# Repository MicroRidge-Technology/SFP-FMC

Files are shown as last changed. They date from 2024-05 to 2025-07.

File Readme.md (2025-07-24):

# FMC SFP Card

This project is designed to allow using sfp cables with the LVDS pins of an FPGA as opposed to the GTX pins. It provides testpoints to monitor the lvds signals with an oscilliscope.

# Pins Used

| FMC Pin | Logical Name | SFP Channel |
| --- | --- | --- |
| D14 | FMC\_LA09\_P | SFP0 rx+ |
| D15 | FMC\_LA09\_N | SFP0 rx- |
| H7 | FMC\_LA02\_P | SFP0 tx+ |
| H8 | FMC\_LA02\_N | SFP0 tx- |
| H22 | FMC\_LA19\_P | SFP1 rx+ |
| H23 | FMC\_LA19\_N | SFP1 rx- |
| H37 | FMC\_LA32\_P | SFP1 tx+ |
| H38 | FMC\_LA32\_N | SFP1 tx- |

# Schematics
Schmatics are available [here](doc/fmc-sfp.pdf)

# Images

Top
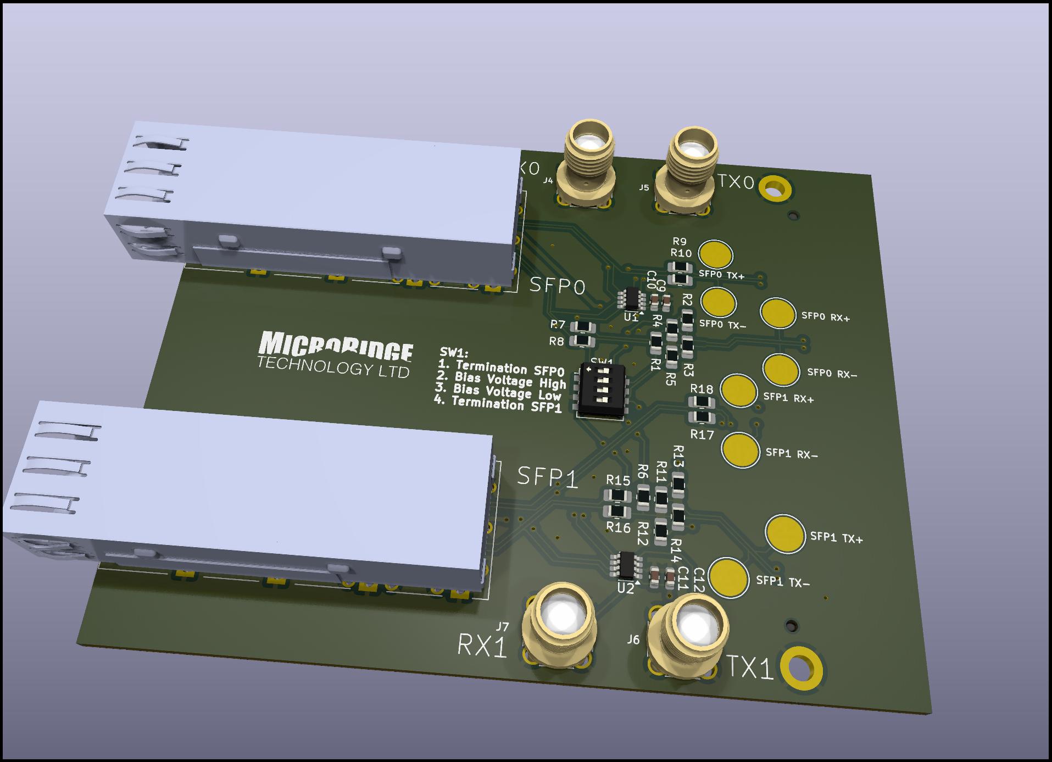
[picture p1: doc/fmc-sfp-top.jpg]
top


Bottom
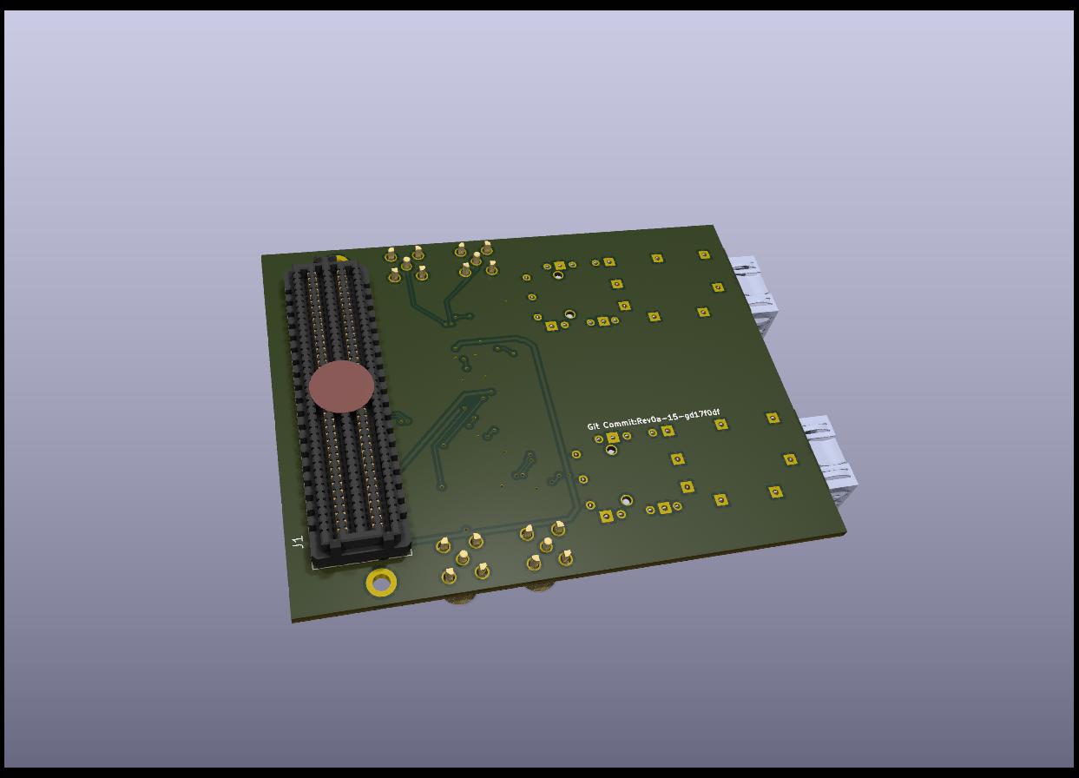
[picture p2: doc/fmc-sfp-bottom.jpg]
bottom


# Limitations 

This board is designed to work with low frequency signals (<200MHz)  GHz+ signals will certainly fail.

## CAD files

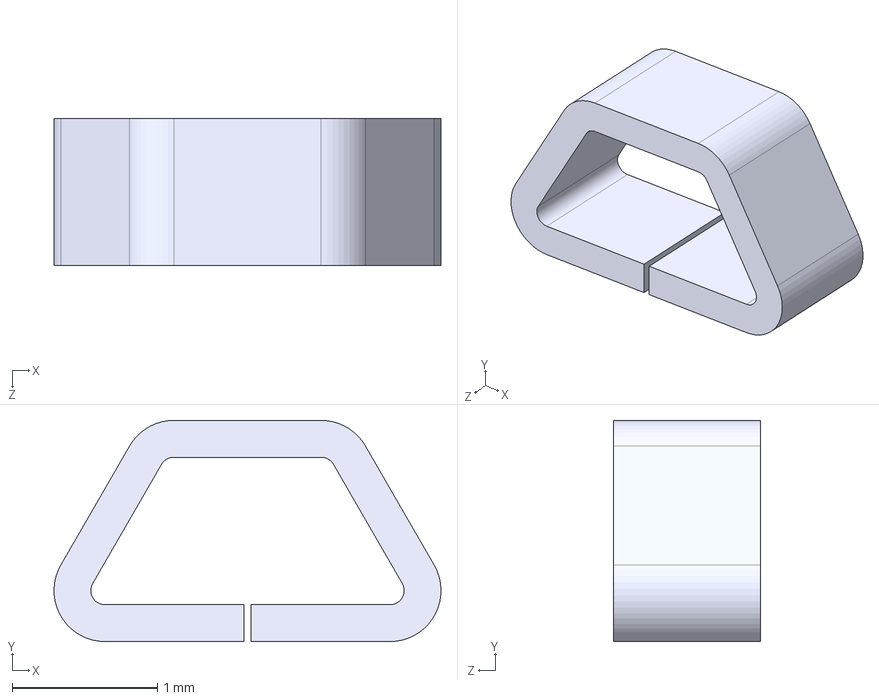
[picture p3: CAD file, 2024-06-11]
3d-models/5015.step
2.67 x 1.52 x 1.02 mm

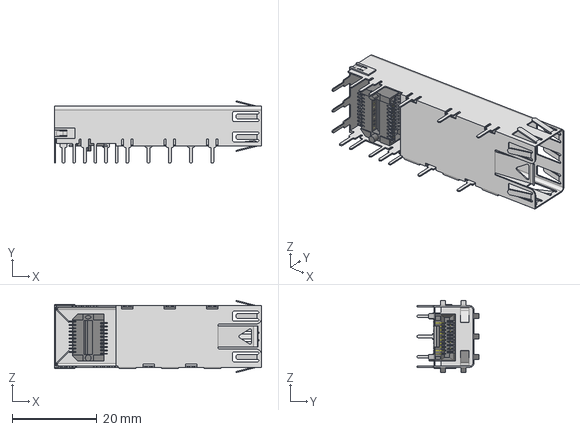
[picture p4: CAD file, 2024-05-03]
3d-models/sfpk-sl.step
48.7 x 14.7 x 17.0 mm

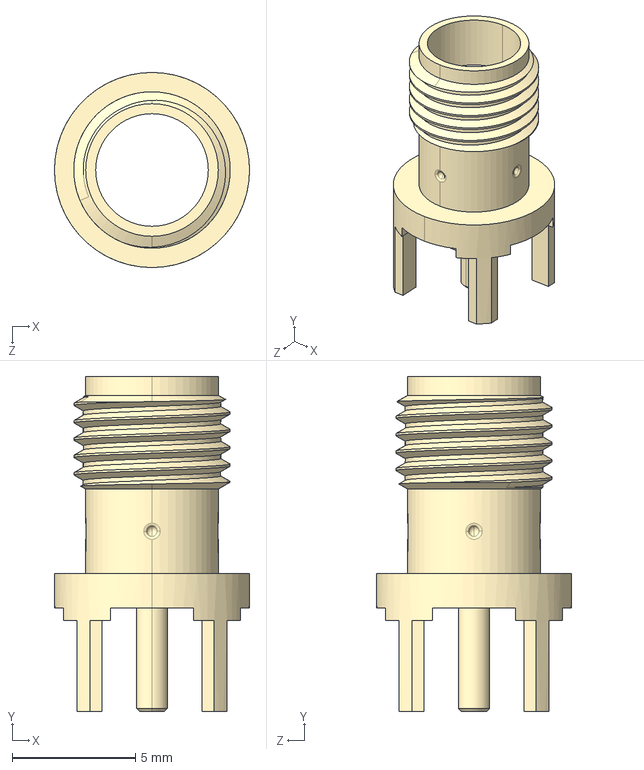
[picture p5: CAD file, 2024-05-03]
3d-models/SMA.step
7.92 x 13.6 x 7.92 mm

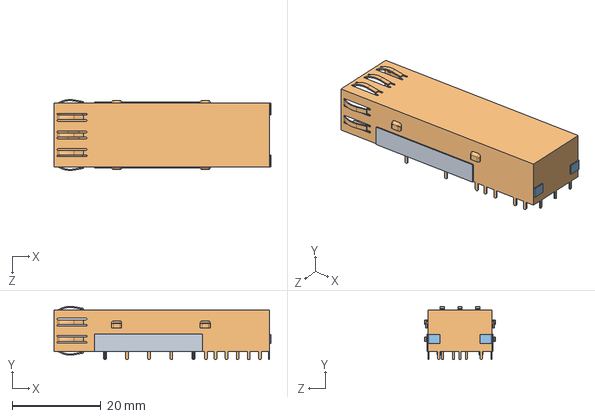
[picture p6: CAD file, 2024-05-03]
3d-models/SFP_cage.step
49.0 x 12.0 x 16.0 mm

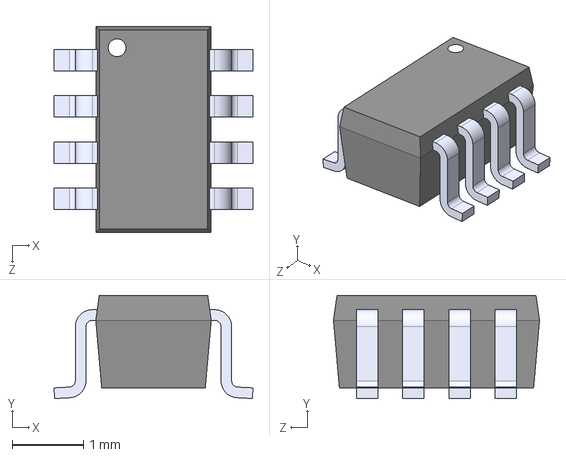
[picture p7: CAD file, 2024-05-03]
3d-models/MAX9113EKA_TT.step
2.80 x 1.45 x 2.90 mm

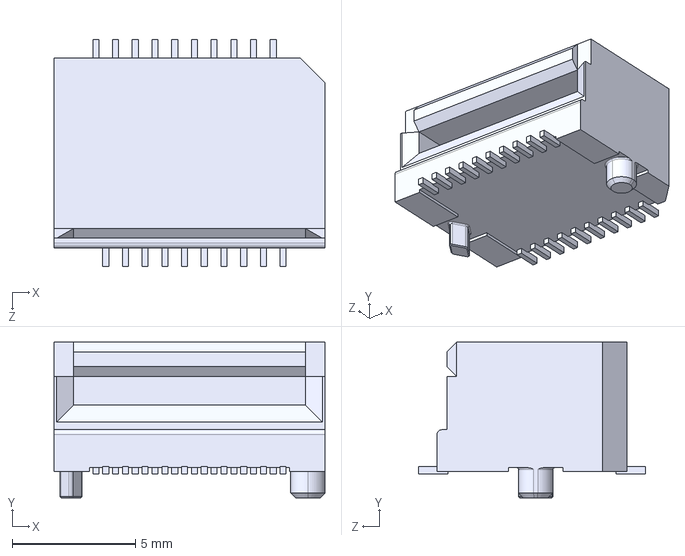
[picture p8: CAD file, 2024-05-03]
3d-models/SFP_connector.step
11.0 x 6.33 x 9.20 mm
UE75A20xxxxx
PinsT_def

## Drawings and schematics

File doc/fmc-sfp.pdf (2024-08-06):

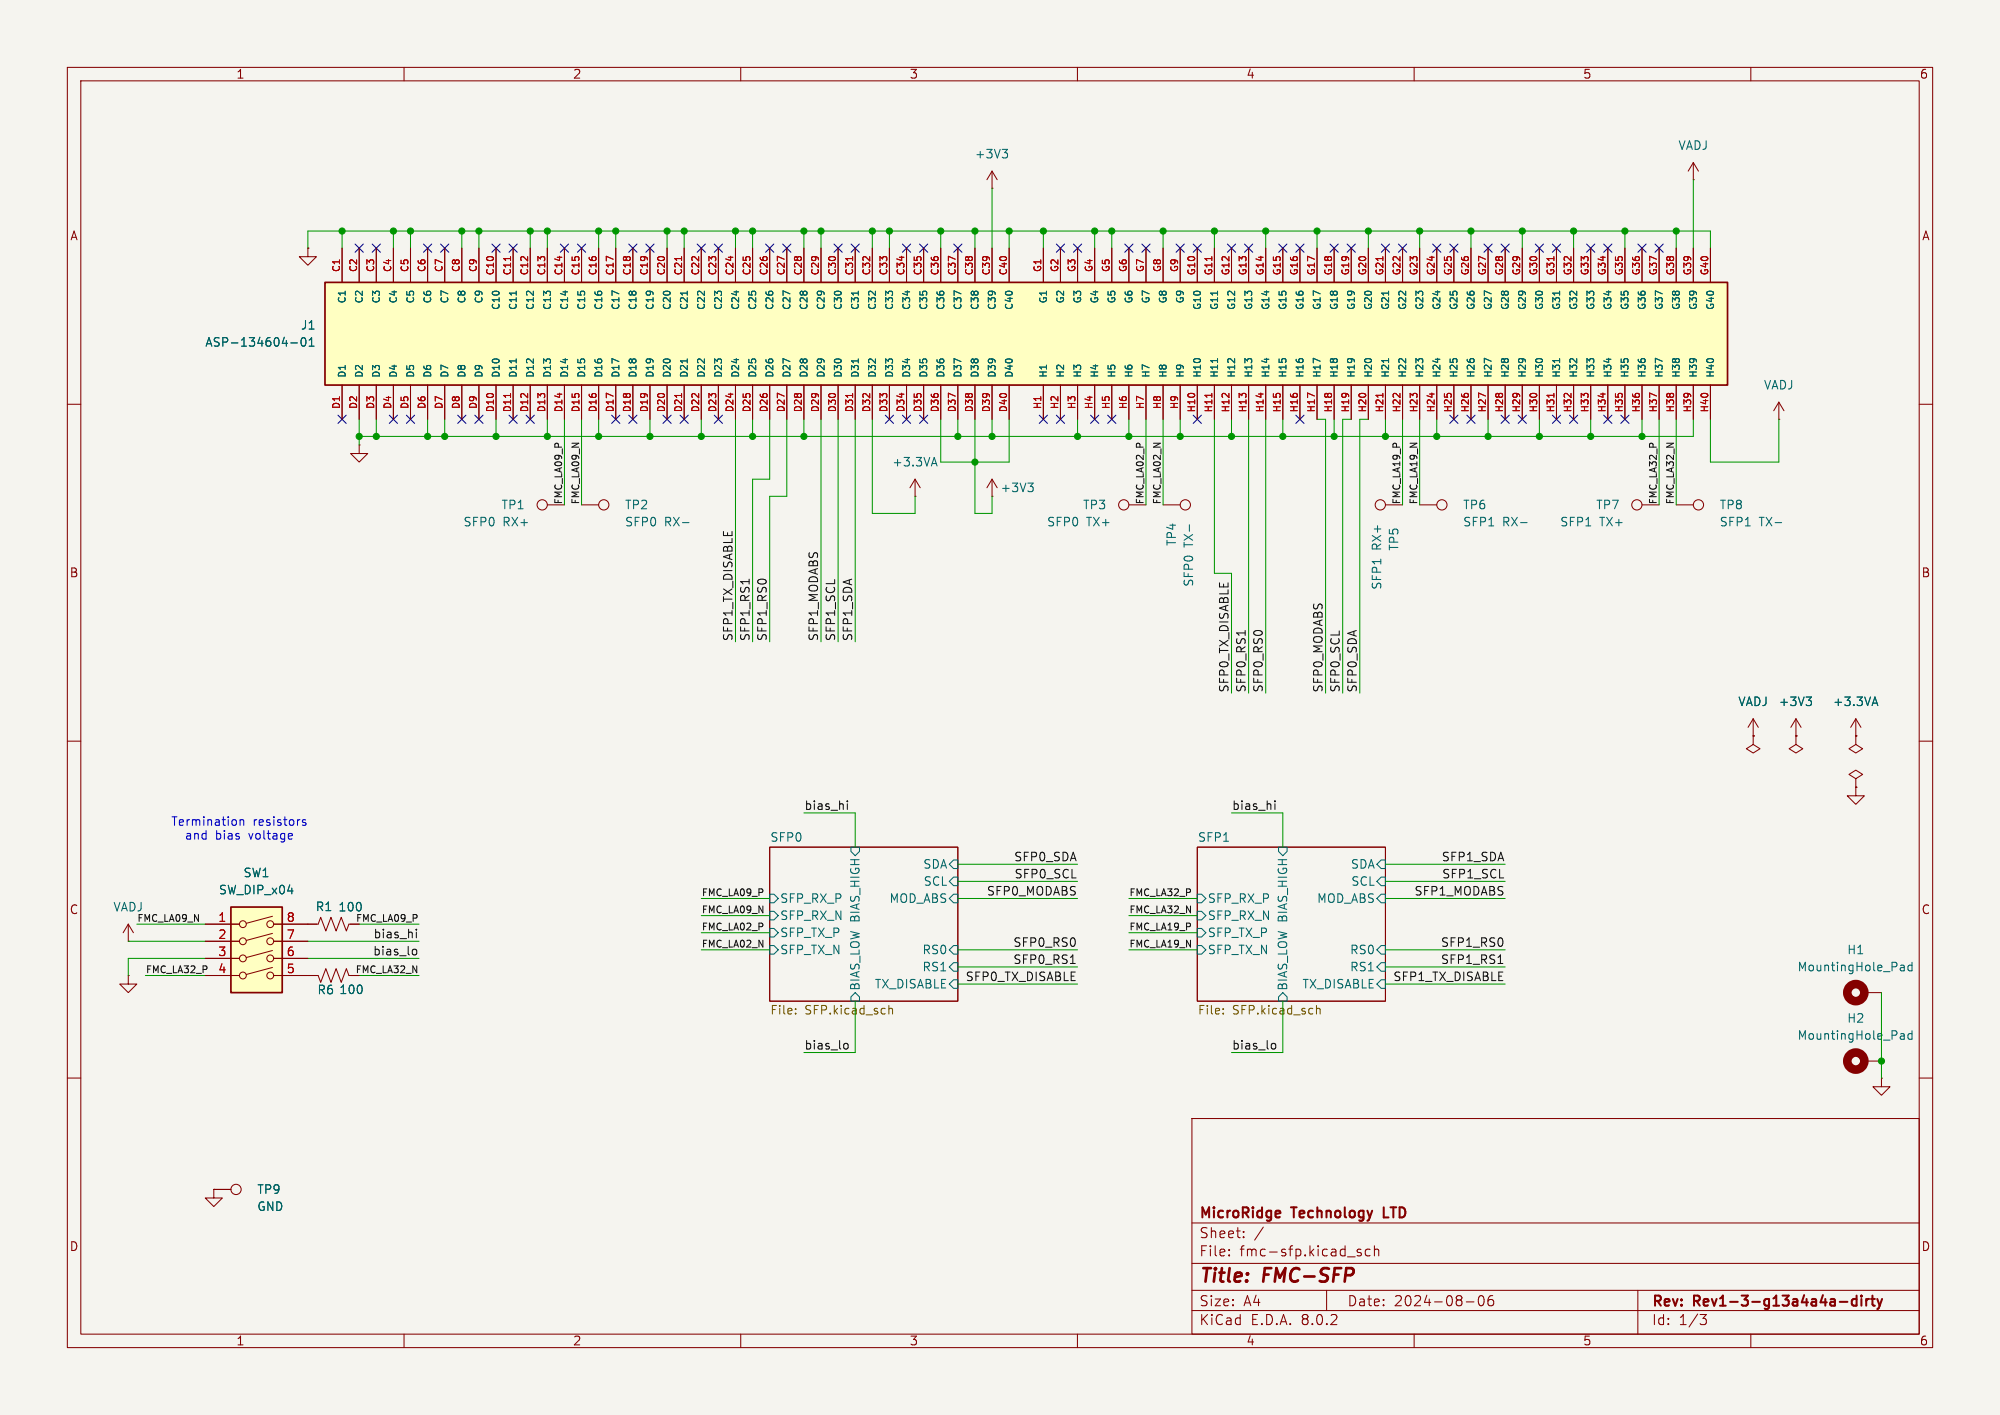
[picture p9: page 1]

Id: 1/3 Title: FMC-SFP

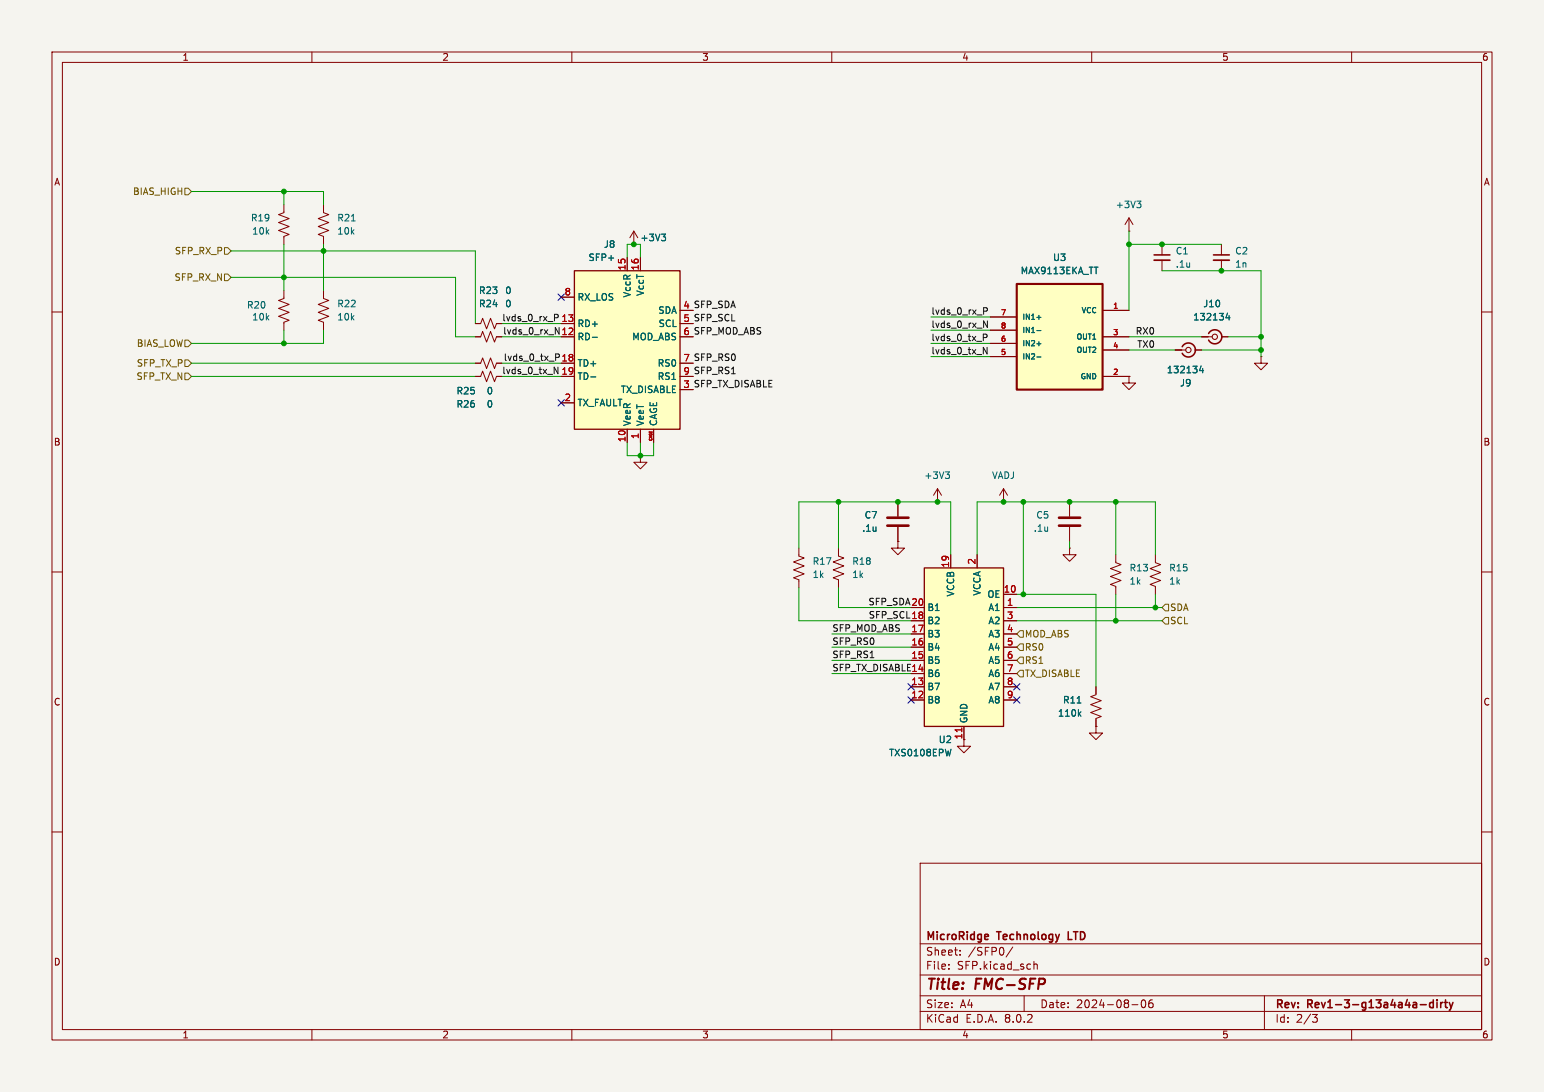
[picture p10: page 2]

1 VeeR 10 RD- 12 RD+ 13 VccR 15 VccT 16 TD+ 18 TD- 19 TX_FAULT 2 TX_DISABLE 3 SDA 4 SCL 5 MOD_ABS 6 RS0 7 RX_LOS 8 RS1 9 CAGE CAGE J8 SFP+ A1 1 OE 10 GND 11 B8 12 B7 13 B6 14 B5 15 B4 16 B3 17 B2 18 VCCB 19 VCCA

1 VeeR 10 RD- 12 RD+ 13 VccR 15 VccT 16 TD+ 18 TD- 19 TX_FAULT 2 TX_DISABLE 3 SDA 4 SCL 5 MOD_ABS 6 RS0 7 RX_LOS 8 RS1 9 CAGE CAGE U2 TXS0108EPW

Id: 2/3 Title: FMC-SFP

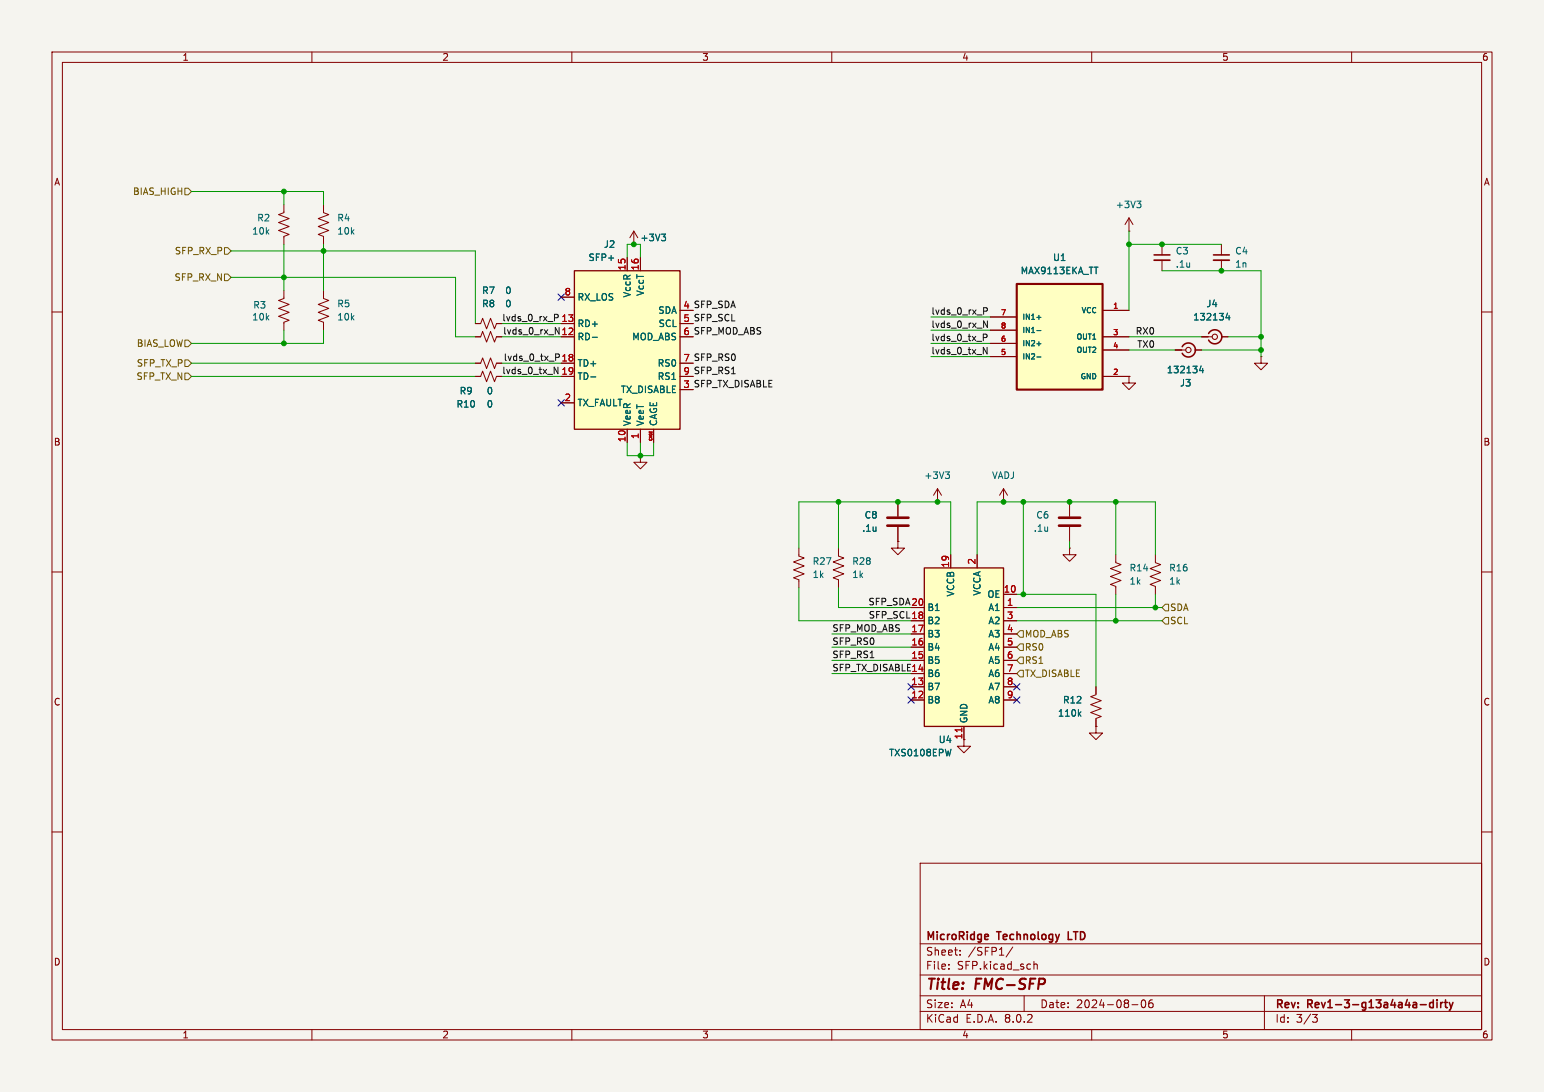
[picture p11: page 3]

1 VeeR 10 RD- 12 RD+ 13 VccR 15 VccT 16 TD+ 18 TD- 19 TX_FAULT 2 TX_DISABLE 3 SDA 4 SCL 5 MOD_ABS 6 RS0 7 RX_LOS 8 RS1 9 CAGE CAGE J2 SFP+ A1 1 OE 10 GND 11 B8 12 B7 13 B6 14 B5 15 B4 16 B3 17 B2 18 VCCB 19 VCCA

1 VeeR 10 RD- 12 RD+ 13 VccR 15 VccT 16 TD+ 18 TD- 19 TX_FAULT 2 TX_DISABLE 3 SDA 4 SCL 5 MOD_ABS 6 RS0 7 RX_LOS 8 RS1 9 CAGE CAGE U4 TXS0108EPW

Id: 3/3 Title: FMC-SFP

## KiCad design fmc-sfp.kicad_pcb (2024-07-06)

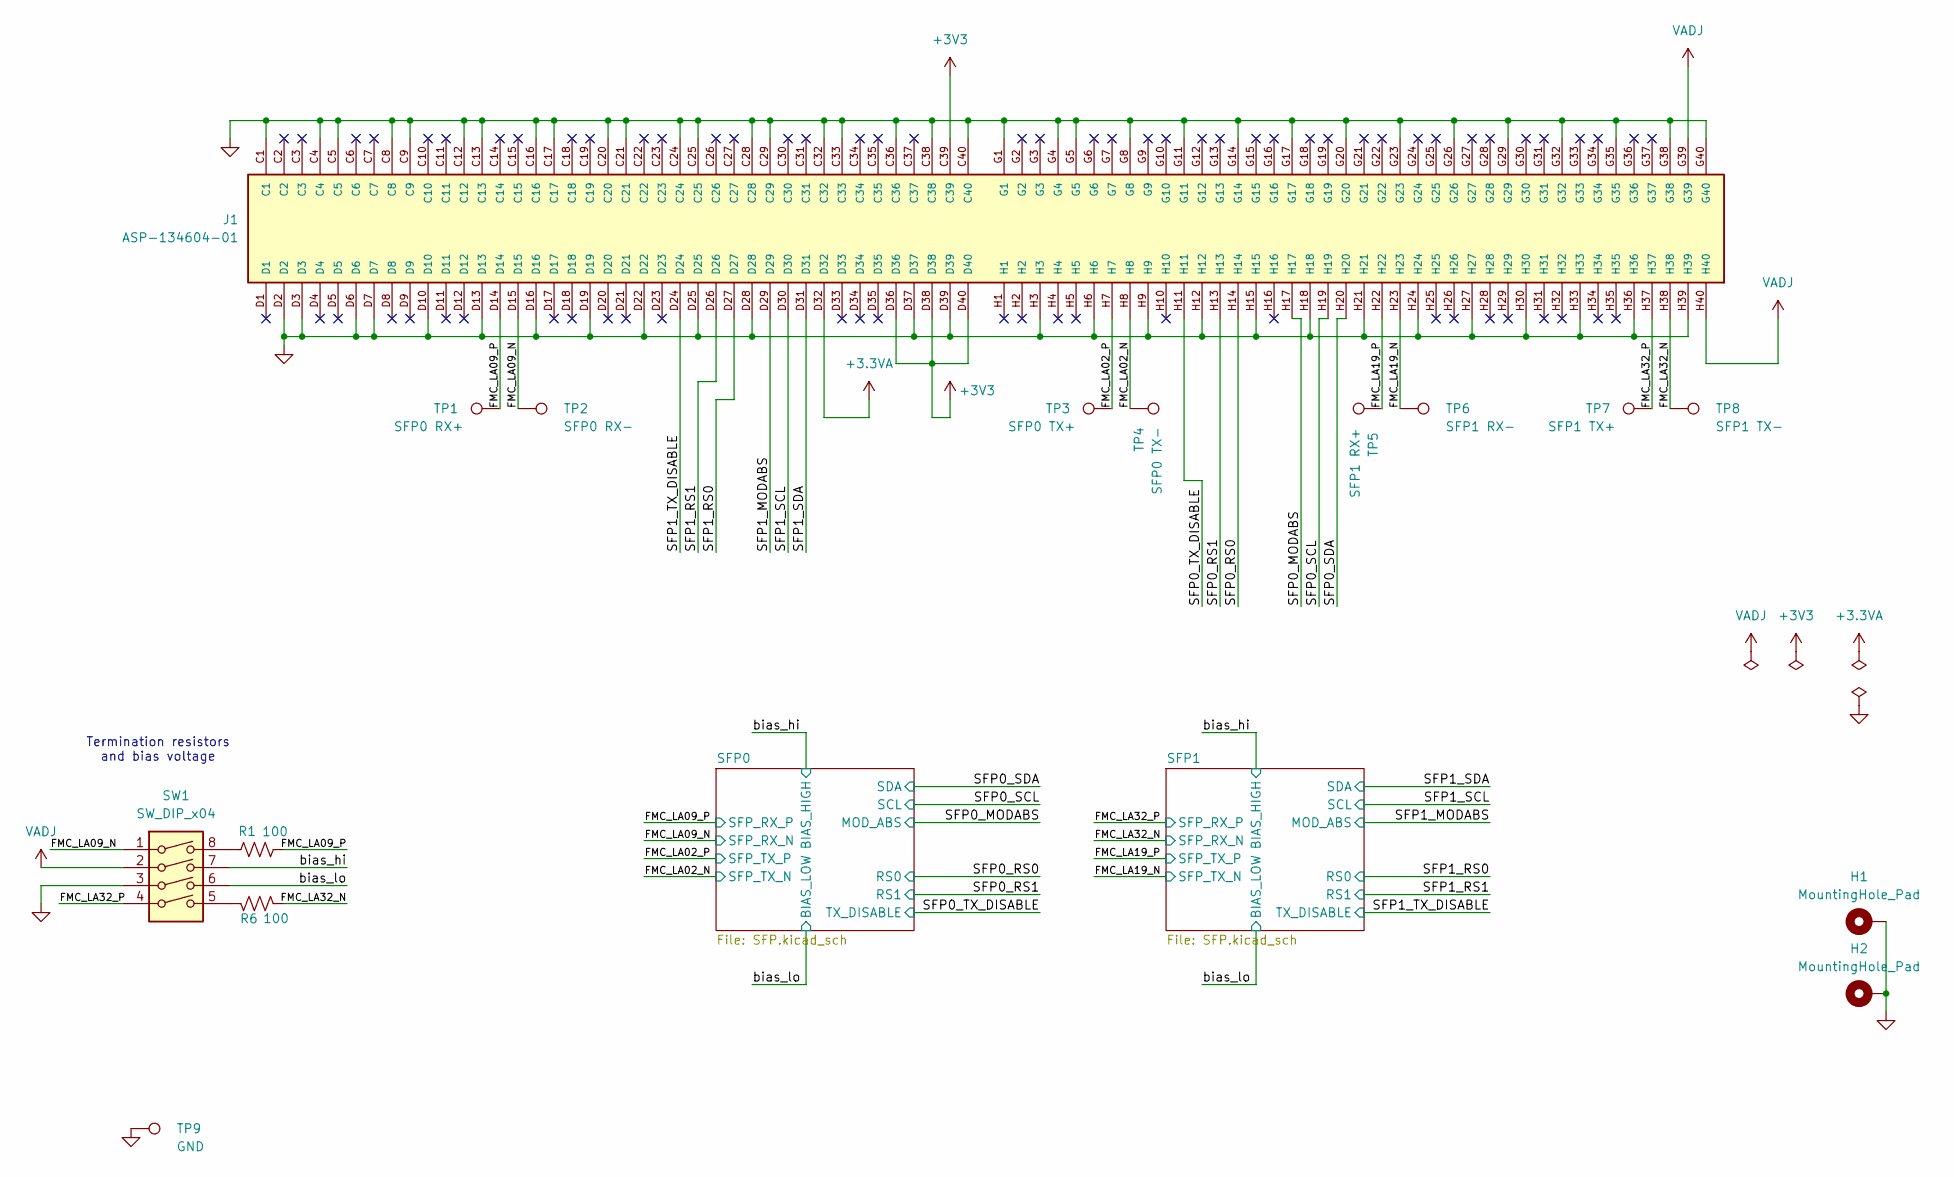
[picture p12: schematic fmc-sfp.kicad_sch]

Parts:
H1, H2: MountingHole_Pad; MountingHole_2.7mm_M2.5_ISO14580_Pad
J1: ASP-134604-01; SAMTEC_ASP-134604-01; PARTREV S
R1, R6: 100; R_0805_2012Metric_Pad1.20x1.40mm_HandSolder; MPN 0805W8F1000T5E
SW1: SW_DIP_x04; SW_DIP_SPSTx04_Slide_KingTek_DSHP04TS_W7.62mm_P1.27mm; MPN DSHP04TSGET
TP1: SFP0 RX+; TestPoint_Pad_D2.5mm
TP2: SFP0 RX-; TestPoint_Pad_D2.5mm
TP3: SFP0 TX+; TestPoint_Pad_D2.5mm
TP4: SFP0 TX-; TestPoint_Pad_D2.5mm
TP5: SFP1 RX+; TestPoint_Pad_D2.5mm
TP6: SFP1 RX-; TestPoint_Pad_D2.5mm
TP7: SFP1 TX+; TestPoint_Pad_D2.5mm
TP8: SFP1 TX-; TestPoint_Pad_D2.5mm
TP9: GND; TestPoint_Keystone_5015_Micro-Minature; MPN 5015

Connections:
+3.3VA: J1.D32
+3V3: J1.C39, J1.D36, J1.D38, J1.D40; also elsewhere on the board
/FMC_LA02_N: J1.H8, TP4.1; also elsewhere on the board
/FMC_LA02_P: J1.H7, TP3.1; also elsewhere on the board
/FMC_LA09_N: J1.D15, SW1.1, TP2.1; also elsewhere on the board
/FMC_LA09_P: J1.D14, R1.2, TP1.1; also elsewhere on the board
/FMC_LA19_N: J1.H23, TP6.1; also elsewhere on the board
/FMC_LA19_P: J1.H22, TP5.1; also elsewhere on the board
/FMC_LA32_N: J1.H38, R6.2, TP8.1; also elsewhere on the board
/FMC_LA32_P: J1.H37, SW1.4, TP7.1; also elsewhere on the board
/SFP0_MODABS: J1.H17; also elsewhere on the board
/SFP0_RS0: J1.H14; also elsewhere on the board
/SFP0_RS1: J1.H13; also elsewhere on the board
/SFP0_SCL: J1.H19; also elsewhere on the board
/SFP0_SDA: J1.H20; also elsewhere on the board
/SFP0_TX_DISABLE: J1.H11; also elsewhere on the board
/SFP1_MODABS: J1.D29; also elsewhere on the board
/SFP1_RS0: J1.D27; also elsewhere on the board
/SFP1_RS1: J1.D26; also elsewhere on the board
/SFP1_SCL: J1.D30; also elsewhere on the board
/SFP1_SDA: J1.D31; also elsewhere on the board
/SFP1_TX_DISABLE: J1.D24; also elsewhere on the board
/bias_hi: SW1.7; also elsewhere on the board
/bias_lo: SW1.6; also elsewhere on the board
GND: H1.1, H2.1, J1.C1, J1.C4, J1.C5, J1.C8, J1.C9, J1.C12, J1.C13, J1.C16, J1.C17, J1.C20, J1.C21, J1.C24, J1.C25, J1.C28, J1.C29, J1.C32, J1.C33, J1.C36, J1.C38, J1.C40, J1.D2, J1.D3, J1.D6, J1.D7, J1.D10, J1.D13, J1.D16, J1.D19, J1.D22, J1.D25, J1.D28, J1.D37, J1.D39, J1.G1, J1.G4, J1.G5, J1.G8, J1.G11, J1.G14, J1.G17, J1.G20, J1.G23, J1.G26, J1.G29, J1.G32, J1.G35, J1.G38, J1.G40, J1.H3, J1.H6, J1.H9, J1.H12, J1.H15, J1.H18, J1.H21, J1.H24, J1.H27, J1.H30, J1.H33, J1.H36, J1.H39, SW1.3, TP9.1; also elsewhere on the board
unnamed: R1.1, SW1.8
unnamed: R6.1, SW1.5
VADJ: J1.G39, J1.H40, SW1.2; also elsewhere on the board

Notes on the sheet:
Termination resistors and bias voltage

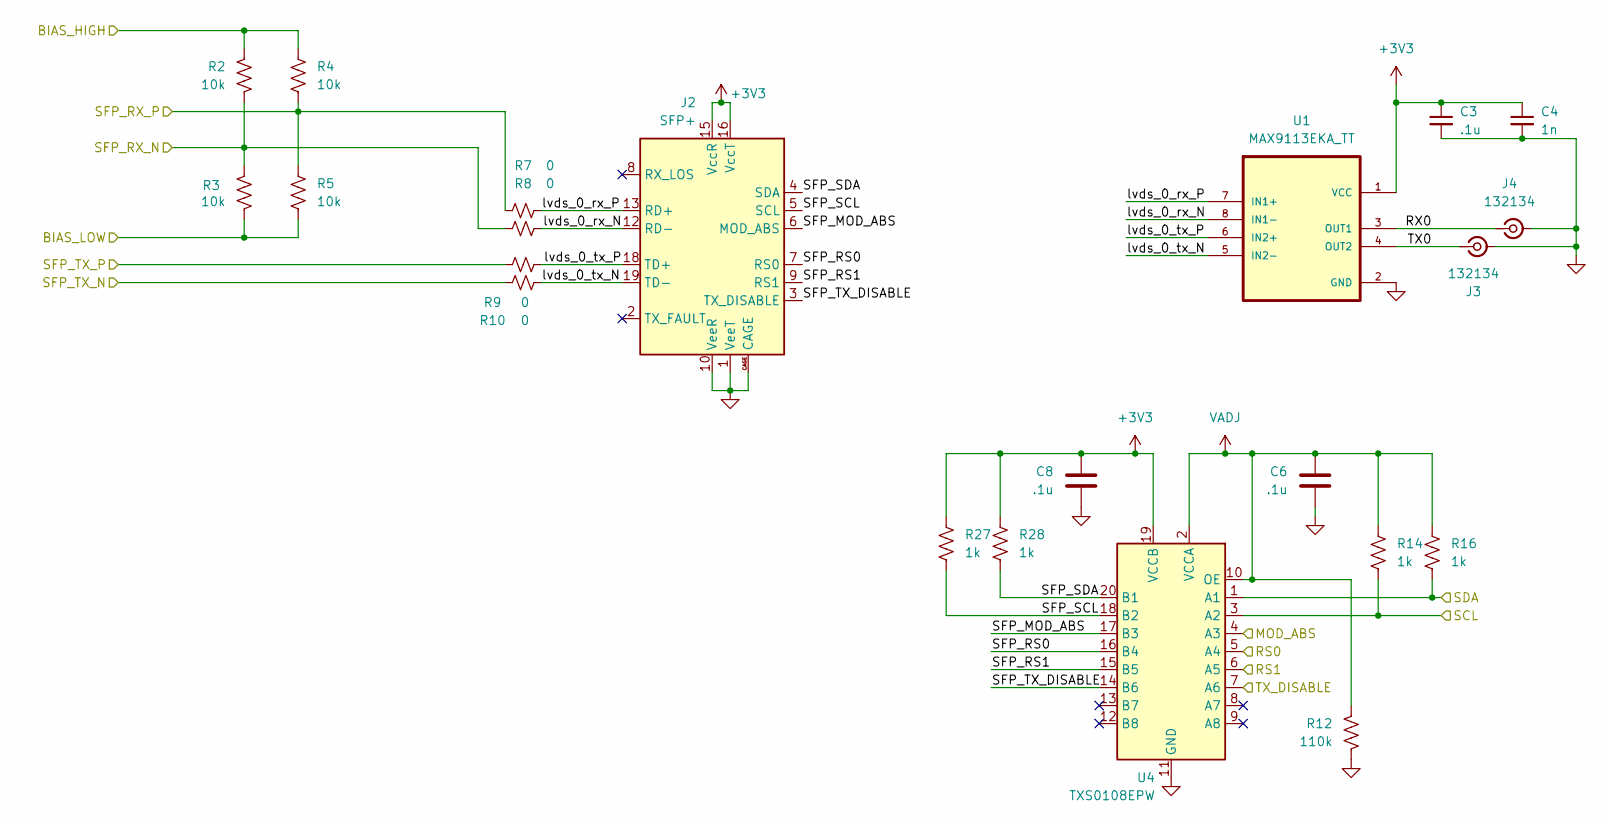
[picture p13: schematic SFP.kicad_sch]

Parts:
C3, C6, C8: .1u; C_0603_1608Metric; MPN C0603C104M5RAC7867
C4: 1n; C_0603_1608Metric; MPN C0603C102K5RAC7867
J2: SFP+; SFP_and_Cage; MPN SFPK-SL
J3, J4: 132134; SMA_Amphenol_132134_Vertical; MPN 132134
R2, R3, R4, R5: 10k; R_0805_2012Metric_Pad1.20x1.40mm_HandSolder; MPN 0805W8F1002T5E
R7, R8, R9, R10: 0; R_0805_2012Metric_Pad1.20x1.40mm_HandSolder; MPN 0805W8F0000T5E
R12: 110k; R_0805_2012Metric_Pad1.20x1.40mm_HandSolder; MPN 0805W8F1103T5E
R14, R16, R27, R28: 1k; R_0805_2012Metric_Pad1.20x1.40mm_HandSolder; MPN 0805W8F1001T5E
U1: MAX9113EKA_TT; SOT-23-8; MPN MAX9113EKA+T
U4: TXS0108EPW; TSSOP-20_4.4x6.5mm_P0.65mm; MPN TXS0108EPW

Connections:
+3V3: C3.1, C4.1, C8.1, J2.15 (VccR), J2.16 (VccT), R27.1, R28.1, U1.1 (VCC), U4.19 (VCCB); also elsewhere on the board
/FMC_LA19_N: R10.1; also elsewhere on the board
/FMC_LA19_P: R9.1; also elsewhere on the board
/FMC_LA32_N: R2.2, R3.1, R8.1; also elsewhere on the board
/FMC_LA32_P: R4.2, R5.1, R7.1; also elsewhere on the board
/SFP1/RX0: J4.1 (In), U1.3 (OUT1)
/SFP1/SFP_MOD_ABS: J2.6 (MOD_ABS), U4.17 (B3)
/SFP1/SFP_RS0: J2.7 (RS0), U4.16 (B4)
/SFP1/SFP_RS1: J2.9 (RS1), U4.15 (B5)
/SFP1/SFP_SCL: J2.5 (SCL), R27.2, U4.18 (B2)
/SFP1/SFP_SDA: J2.4 (SDA), R28.2, U4.20 (B1)
/SFP1/SFP_TX_DISABLE: J2.3 (TX_DISABLE), U4.14 (B6)
/SFP1/TX0: J3.1 (In), U1.4 (OUT2)
/SFP1/lvds_0_rx_N: J2.12 (RD-), R8.2, U1.8 (IN1-)
/SFP1/lvds_0_rx_P: J2.13 (RD+), R7.2, U1.7 (IN1+)
/SFP1/lvds_0_tx_N: J2.19 (TD-), R10.2, U1.5 (IN2-)
/SFP1/lvds_0_tx_P: J2.18 (TD+), R9.2, U1.6 (IN2+)
/SFP1_MODABS: U4.4 (A3); also elsewhere on the board
/SFP1_RS0: U4.5 (A4); also elsewhere on the board
/SFP1_RS1: U4.6 (A5); also elsewhere on the board
/SFP1_SCL: R14.2, U4.3 (A2); also elsewhere on the board
/SFP1_SDA: R16.2, U4.1 (A1); also elsewhere on the board
/SFP1_TX_DISABLE: U4.7 (A6); also elsewhere on the board
/bias_hi: R2.1, R4.1; also elsewhere on the board
/bias_lo: R3.2, R5.2; also elsewhere on the board
GND: C3.2, C4.2, C6.2, C8.2, J2.1 (VeeT), J2.10 (VeeR), J2.11 (VeeR), J2.14 (VeeR), J2.17 (VeeT), J2.20 (VeeT), J2.CAGE, J3.2 (Ext), J4.2 (Ext), R12.2, U1.2 (GND), U4.11 (GND); also elsewhere on the board
VADJ: C6.1, R12.1, R14.1, R16.1, U4.2 (VCCA), U4.10 (OE); also elsewhere on the board

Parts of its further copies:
C1, C5, C7: .1u; C_0603_1608Metric; MPN C0603C104M5RAC7867
C2: 1n; C_0603_1608Metric; MPN C0603C102K5RAC7867
J8: SFP+; SFP_and_Cage; MPN SFPK-SL
J9, J10: 132134; SMA_Amphenol_132134_Vertical; MPN 132134
R11: 110k; R_0805_2012Metric_Pad1.20x1.40mm_HandSolder; MPN 0805W8F1103T5E
R13, R15, R17, R18: 1k; R_0805_2012Metric_Pad1.20x1.40mm_HandSolder; MPN 0805W8F1001T5E
R19, R20, R21, R22: 10k; R_0805_2012Metric_Pad1.20x1.40mm_HandSolder; MPN 0805W8F1002T5E
R23, R24, R25, R26: 0; R_0805_2012Metric_Pad1.20x1.40mm_HandSolder; MPN 0805W8F0000T5E
U2: TXS0108EPW; TSSOP-20_4.4x6.5mm_P0.65mm; MPN TXS0108EPW
U3: MAX9113EKA_TT; SOT-23-8; MPN MAX9113EKA+T

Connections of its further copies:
+3V3: C1.1, C2.1, C7.1, J8.15 (VccR), J8.16 (VccT), R17.1, R18.1, U2.19 (VCCB), U3.1 (VCC); also elsewhere on the board
/FMC_LA02_N: R26.1; also elsewhere on the board
/FMC_LA02_P: R25.1; also elsewhere on the board
/FMC_LA09_N: R19.2, R20.1, R24.1; also elsewhere on the board
/FMC_LA09_P: R21.2, R22.1, R23.1; also elsewhere on the board
/SFP0/RX0: J10.1 (In), U3.3 (OUT1)
/SFP0/SFP_MOD_ABS: J8.6 (MOD_ABS), U2.17 (B3)
/SFP0/SFP_RS0: J8.7 (RS0), U2.16 (B4)
/SFP0/SFP_RS1: J8.9 (RS1), U2.15 (B5)
/SFP0/SFP_SCL: J8.5 (SCL), R17.2, U2.18 (B2)
/SFP0/SFP_SDA: J8.4 (SDA), R18.2, U2.20 (B1)
/SFP0/SFP_TX_DISABLE: J8.3 (TX_DISABLE), U2.14 (B6)
/SFP0/TX0: J9.1 (In), U3.4 (OUT2)
/SFP0/lvds_0_rx_N: J8.12 (RD-), R24.2, U3.8 (IN1-)
/SFP0/lvds_0_rx_P: J8.13 (RD+), R23.2, U3.7 (IN1+)
/SFP0/lvds_0_tx_N: J8.19 (TD-), R26.2, U3.5 (IN2-)
/SFP0/lvds_0_tx_P: J8.18 (TD+), R25.2, U3.6 (IN2+)
/SFP0_MODABS: U2.4 (A3); also elsewhere on the board
/SFP0_RS0: U2.5 (A4); also elsewhere on the board
/SFP0_RS1: U2.6 (A5); also elsewhere on the board
/SFP0_SCL: R13.2, U2.3 (A2); also elsewhere on the board
/SFP0_SDA: R15.2, U2.1 (A1); also elsewhere on the board
/SFP0_TX_DISABLE: U2.7 (A6); also elsewhere on the board
/bias_hi: R19.1, R21.1; also elsewhere on the board
/bias_lo: R20.2, R22.2; also elsewhere on the board
GND: C1.2, C2.2, C5.2, C7.2, J8.1 (VeeT), J8.10 (VeeR), J8.11 (VeeR), J8.14 (VeeR), J8.17 (VeeT), J8.20 (VeeT), J8.CAGE, J9.2 (Ext), J10.2 (Ext), R11.2, U2.11 (GND), U3.2 (GND); also elsewhere on the board
VADJ: C5.1, R11.1, R13.1, R15.1, U2.2 (VCCA), U2.10 (OE); also elsewhere on the board

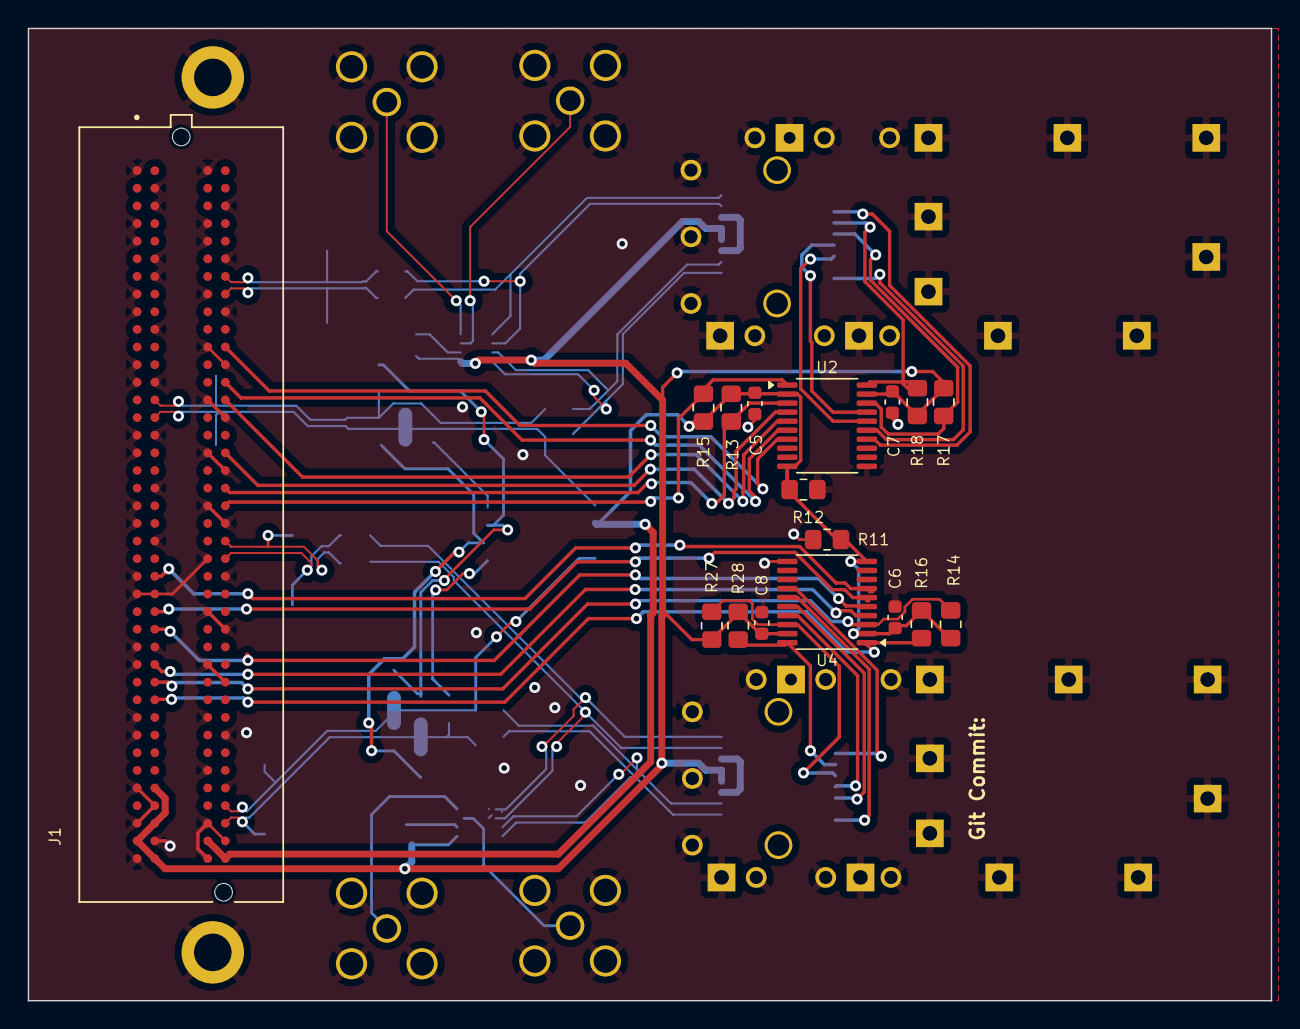
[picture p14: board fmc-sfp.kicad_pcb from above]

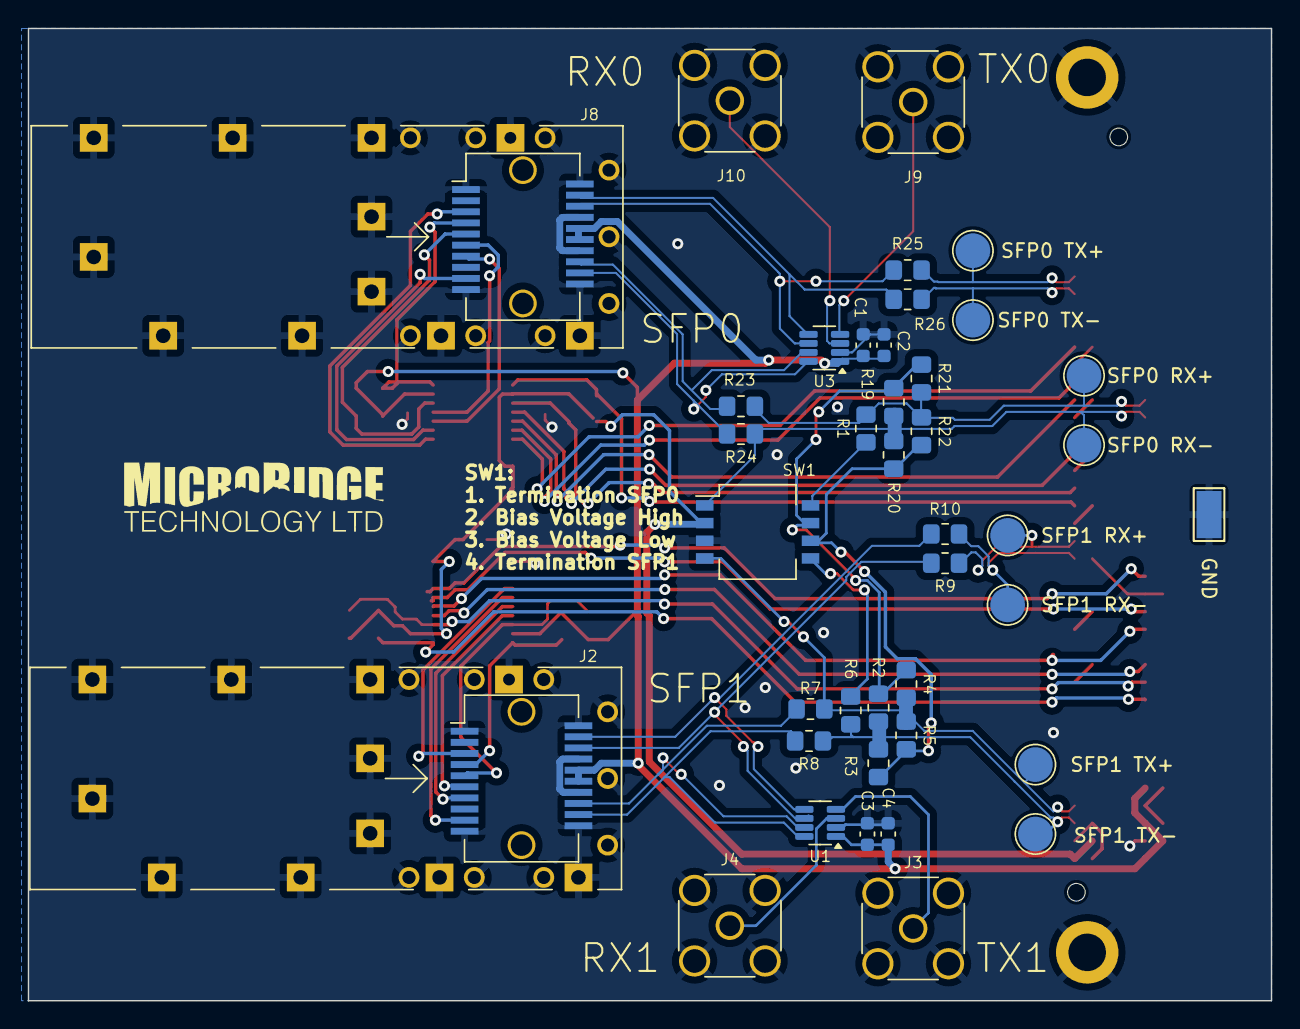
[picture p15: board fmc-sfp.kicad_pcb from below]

Board: 4 copper layers, 89.5 x 70.0 mm, 59 parts (40 on the bottom side), 51 nets.

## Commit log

2024-05-03 change fmc connector model
    [fmc-sfp.kicad_pcb]
2024-05-03 add 3d models
    [fmc-sfp.kicad_pcb]
2024-05-03 change schematic directory
2024-05-03 update after Phil review
    [SFP.kicad_sch, fmc-sfp.kicad_pcb, fmc-sfp.kicad_sch]
2024-05-03 update schematic
2024-05-03 add sfp module step model
    [sfpk-sl.step]
2024-05-03 Minor tweaks to sfp cage position, fix silkscreen s/RX/TX/
    [fmc-sfp.kicad_pcb]
2024-05-04 move termination resistors to FPGA side of capacitors
    [fmc-sfp.kicad_pcb, fmc-sfp.kicad_sch]
2024-05-04 clean up a trace
    [fmc-sfp.kicad_pcb]
2024-05-08 update capacitor part numbers
    [SFP.kicad_sch, fmc-sfp.kicad_pcb, fmc-sfp.kicad_sch]
2024-05-08 connect all grounds for fmc connector
    [fmc-sfp.kicad_pcb, fmc-sfp.kicad_sch]
2024-05-08 add fmc footprint to project
2024-05-14 update sfp footprint, add git commit to silkscreen
    [fmc-sfp.kicad_pcb, fmc-sfp.kicad_sch]
2024-05-14 set part number for sfp cage
    [fmc-sfp.kicad_pcb, fmc-sfp.kicad_sch]
2024-05-30 modify title block
    [SFP.kicad_sch, fmc-sfp.kicad_sch]
2024-05-30 Change resistors to 0805, add switch to disable DC Bias
    [fmc-sfp.kicad_pcb, fmc-sfp.kicad_sch]
2024-05-30 add schematic to generated files
2024-05-30 use custom schematic page layout
2024-05-31 remove unused file
    [SFP.kicad_sch]
2024-05-31 fix ERC
    [fmc-sfp.kicad_sch]
2024-05-31 run DRC and generate board files
2024-05-31 fix Vadj symbol
    [fmc-sfp.kicad_sch]
2024-05-31 clean up schematic and pcb
    [fmc-sfp.kicad_pcb, fmc-sfp.kicad_sch]
2024-05-31 make board more symetrical
    [fmc-sfp.kicad_pcb, fmc-sfp.kicad_sch]
2024-05-31 board_files.sh automatically calls docker if necessary
2024-06-11 add single x4 switch and test pads for differential probing
    [fmc-sfp.kicad_pcb, fmc-sfp.kicad_sch]
2024-06-11 fix DRC issues
    [fmc-sfp.kicad_pcb]
2024-06-11 cleanup schematic
    [fmc-sfp.kicad_pcb, fmc-sfp.kicad_sch]
2024-06-11 update documents
    [fmc-sfp.kicad_pcb]
2024-06-11 exclude test points from BOM
    [fmc-sfp.kicad_pcb, fmc-sfp.kicad_sch]
2024-06-11 asthetic cleanup, add ground testpoint
    [5015.step, fmc-sfp.kicad_pcb, fmc-sfp.kicad_sch]
2024-06-14 set SW1 part number
    [fmc-sfp.kicad_pcb, fmc-sfp.kicad_sch]
2024-06-14 move GND TP lable
    [fmc-sfp.kicad_pcb]
2024-06-14 update schematics with I2C
    [SFP.kicad_sch]
2024-06-15 Update layout with i2c
    [SFP.kicad_sch, fmc-sfp.kicad_pcb, fmc-sfp.kicad_sch]
2024-06-15 add level shifter Part Number
    [SFP.kicad_sch, fmc-sfp.kicad_pcb]
2024-06-17 update fills
    [fmc-sfp.kicad_pcb]
2024-06-17 Update MPN of switch
    [fmc-sfp.kicad_pcb, fmc-sfp.kicad_sch]
2024-07-06 fix MPN of 110K resistors
    [SFP.kicad_sch, fmc-sfp.kicad_pcb]
2024-07-26 Update PDF of schematics in doc directory
2024-08-06 Add Title block to other sheets
    [SFP.kicad_sch, fmc-sfp.kicad_sch]
2024-08-06 update title block
    [SFP.kicad_sch, fmc-sfp.kicad_sch]
